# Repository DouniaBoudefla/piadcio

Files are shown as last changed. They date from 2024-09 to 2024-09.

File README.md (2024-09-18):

PIADC-IO

PIADC-IO is a versatile and I/O expansion project designed to enhance the GPIO capabilities of the Raspberry Pi. The project integrates the MCP23S08 I/O expander and the MCP3208 ADC (Analog-to-Digital Converter) with the Raspberry Pi, enabling efficient control of multiple devices and precise analog signal measurements via the SPI protocol. This repository contains all the necessary resources, including schematics, PCB designs, code, and documentation, to set up and use the PIADC-IO system for various applications, such as slow control in experimental setups and monitoring analog inputs.

Features

I/O Expansion: Utilize the MCP23S08 to expand the Raspberry Pi's GPIO capabilities by 8 configurable pins per expander, supporting multiple input/output configurations.
Analog-to-Digital Conversion: Integrate the MCP3208 to enable reading from up to 8 analog input channels with 12-bit resolution.
Power Indication LED: Monitor power status with a controllable LED, which can be managed via the Raspberry Pi.
Modular and Configurable: Easily adapt the system to different hardware setups with a TOML configuration file used to define hardware-specific settings like SPI bus numbers and chip select lines.

Repository Structure

pcb/ - Includes PCB design files and contains the electronic schematics used for the project, designed in KiCad.
src/ - Source code for interacting with the MCP23S08 and MCP3208, including Python classes for each.

Preliminary Configuration

Before starting, you need to enable the SPI function on your Raspberry Pi using 'raspi-config'.
The Raspberry Pi have 2 different SPI bus: one will be known as /dev/spi0.* and the other as /dev/spi1.*.

Enabling SPI1

if '/dev/spi1.0' and '/dev/spi1.1' are not available, you need to enable SPI1 manually:

1. Edit the boot configuration file:

        sudo nano /boot/config.txt

2. Add the following lines at the end of the file to enable SPI1:

        dtparam=spi=on
        dtoverlay=spi1-3cs

3. Save the file and exit the editor (Ctrl + O, Enter, Ctrl + X)
4. Reboot your Raspberry Pi to apply the changes:

        sudo reboot

After rebooting, you should see '/dev/spi1.0' and '/dev/spi1.1' available for use.

Communication with MCP23S08

To communicate with MCP23S08, you need to send and receive data via the SPI interface. Here is how you can read from and write to the the MCP23S08 registers using Python with the 'spidev' library.

Understanding MCP23S08 Communication

Commmand Structure

Communication with the MCP23S08 involves sending a sequence of bytes over the SPI interface. 
Each command generally consists of the following parts:

- Opcode: Determines whether the operation is a read or write
- Register Address: Specifies which register to access
- Data: The value to write to the register (for write operations)

Opcode

Write Opcode: Ox40 (A0=0, A1=0)
Read Opcode: 0x41 (A0=0, A1=0)

The opcode is followed by the register address and then the data byte

Register Address

The MCP23S08 has several registers for configuring and controlling the I/Os. Here are some key registers:

- IODIR (0X00): I/O Direction Register (1 = input, 0 = output)
- GPIO (0x09): GPIO Register (read/write I/O values)
- OLAT (0x0A): Output Latch Register (maintain output values)

Data 

The data byte is the value you write to the register. For read operations, the data byte received from the MCP23S08 will contain the registers's current value.

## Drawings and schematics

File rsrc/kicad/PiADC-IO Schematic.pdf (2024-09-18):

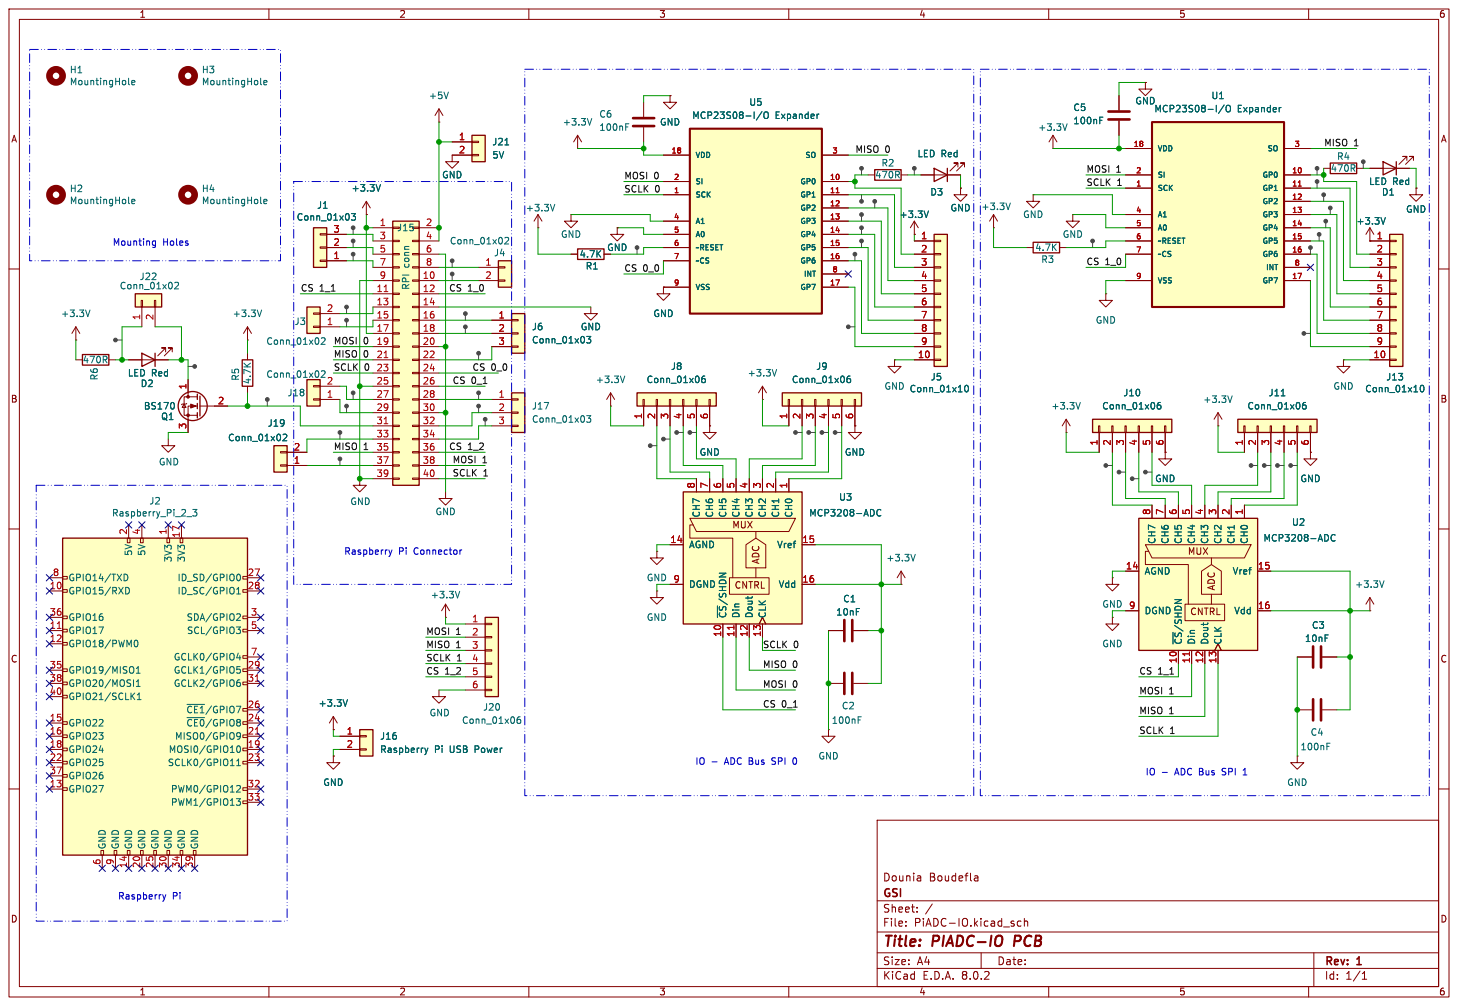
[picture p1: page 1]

6 U1 MCP23S08-I/O Expander SCK 1 GP0 10 GP1 11 GP2 12 GP3 13 GP4 14 GP5 15 GP6 16 GP7 17 VDD 18 SI 2 SO 3 A1 4 A0 5 ~RESET 6 ~CS 7

LED Red GND GND

1 ~{CS}/SHDN 10 Din 11 Dout 12 CLK 13 AGND 14 Vref 15 Vdd 16 CH1

J16 Raspberry Pi USB Power 1

J16 Raspberry Pi USB Power

IO - ADC Bus SPI 0

File: PiADC-IO.kicad_sch Sheet: / GSI Dounia Boudefla

Id: 1/1 Title: PIADC-IO PCB

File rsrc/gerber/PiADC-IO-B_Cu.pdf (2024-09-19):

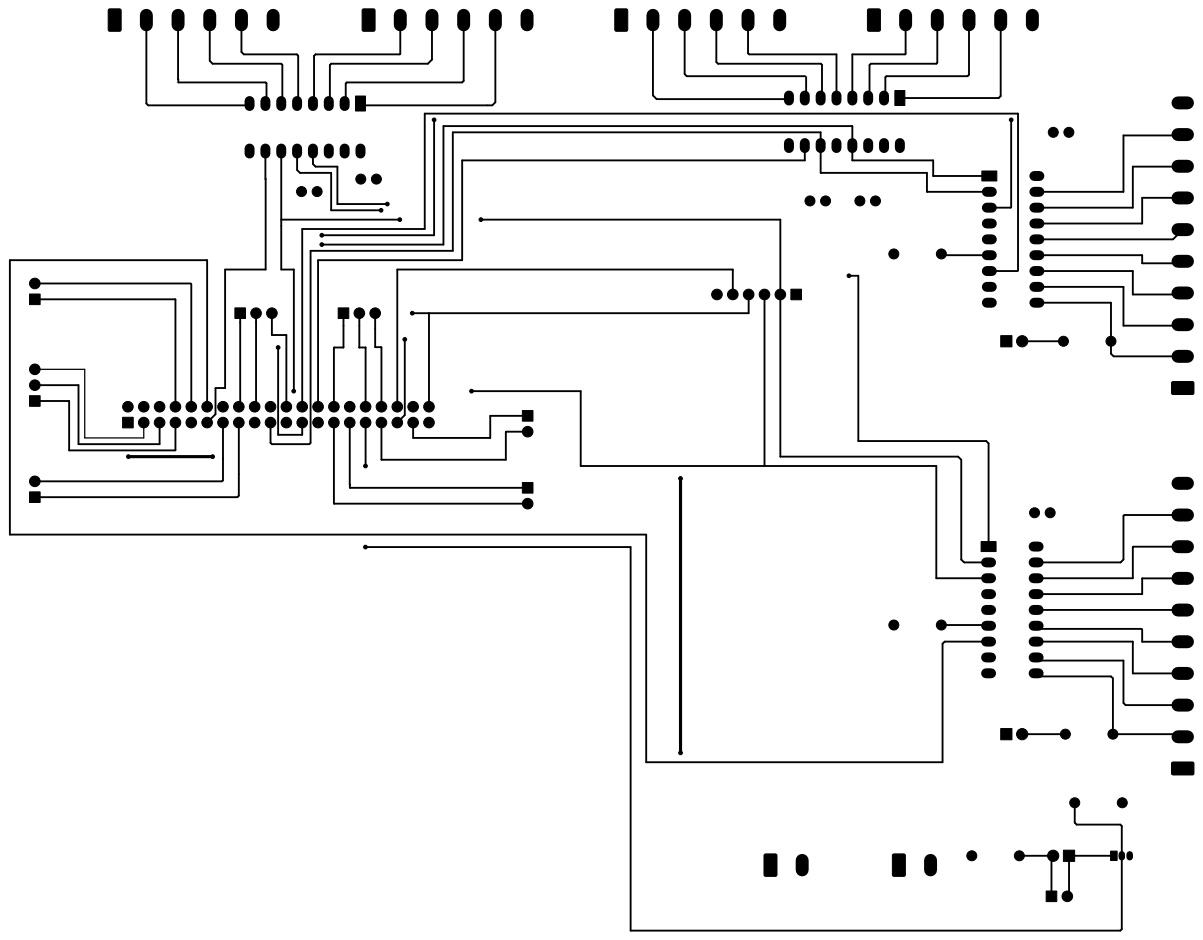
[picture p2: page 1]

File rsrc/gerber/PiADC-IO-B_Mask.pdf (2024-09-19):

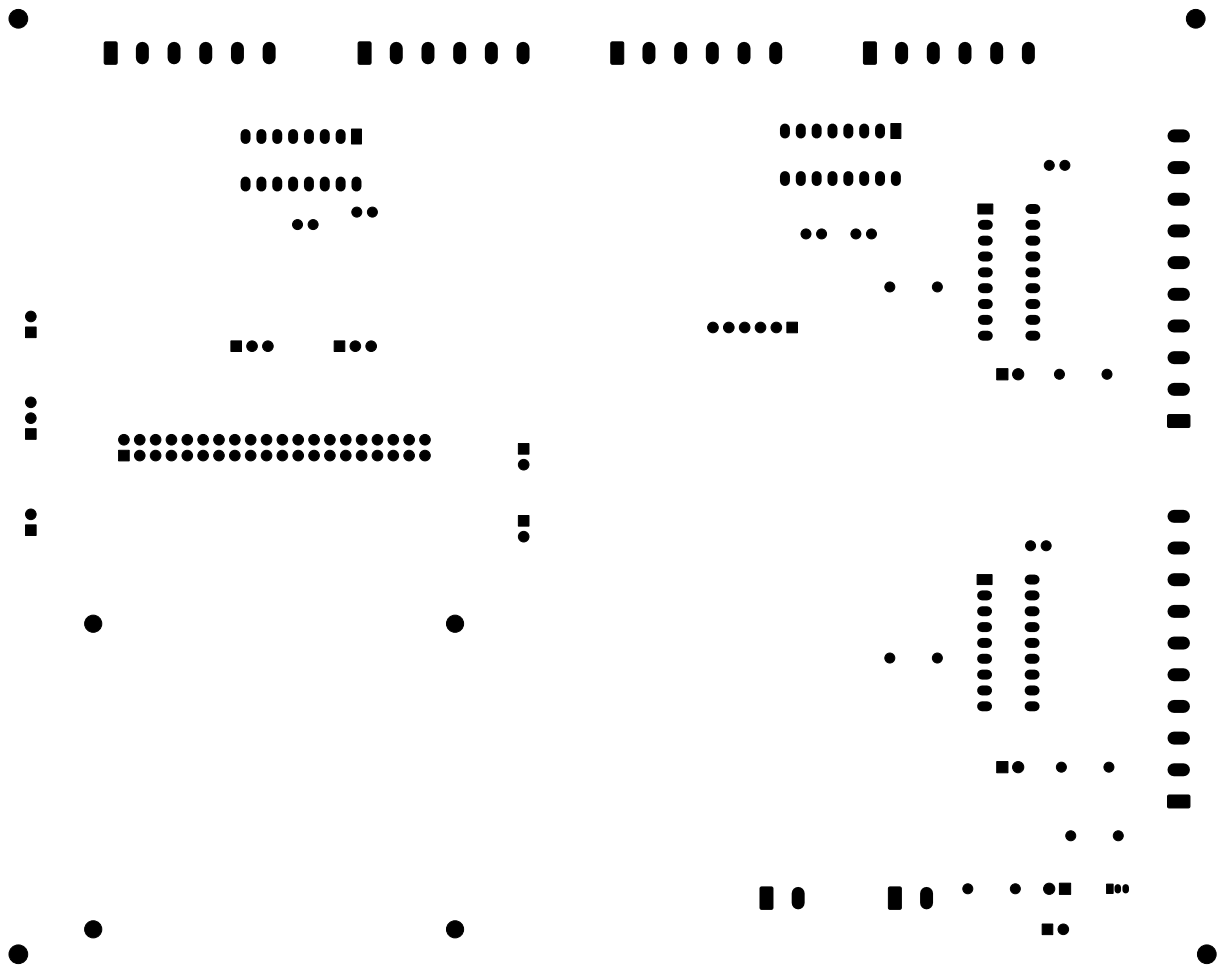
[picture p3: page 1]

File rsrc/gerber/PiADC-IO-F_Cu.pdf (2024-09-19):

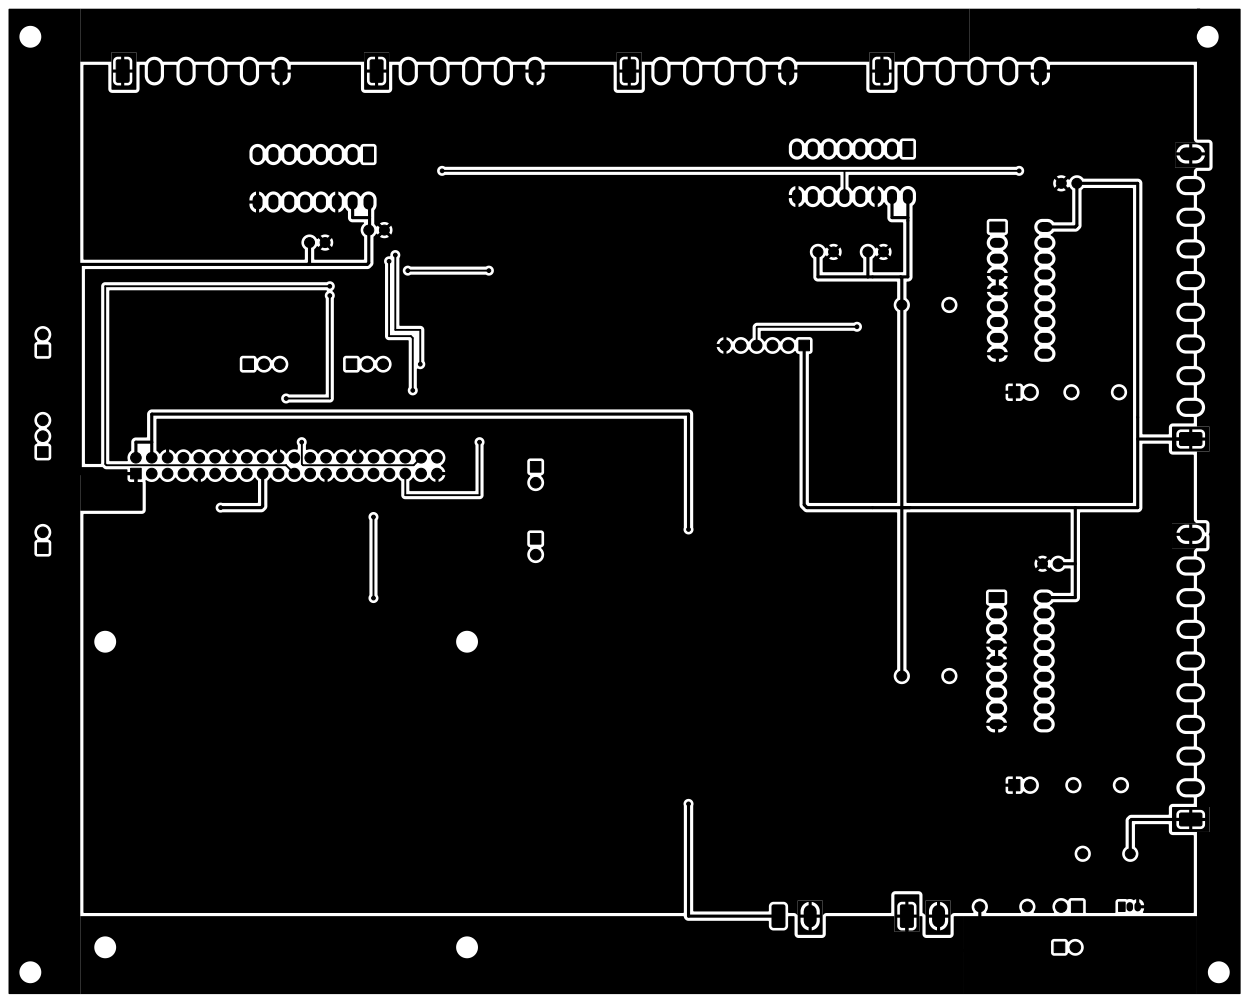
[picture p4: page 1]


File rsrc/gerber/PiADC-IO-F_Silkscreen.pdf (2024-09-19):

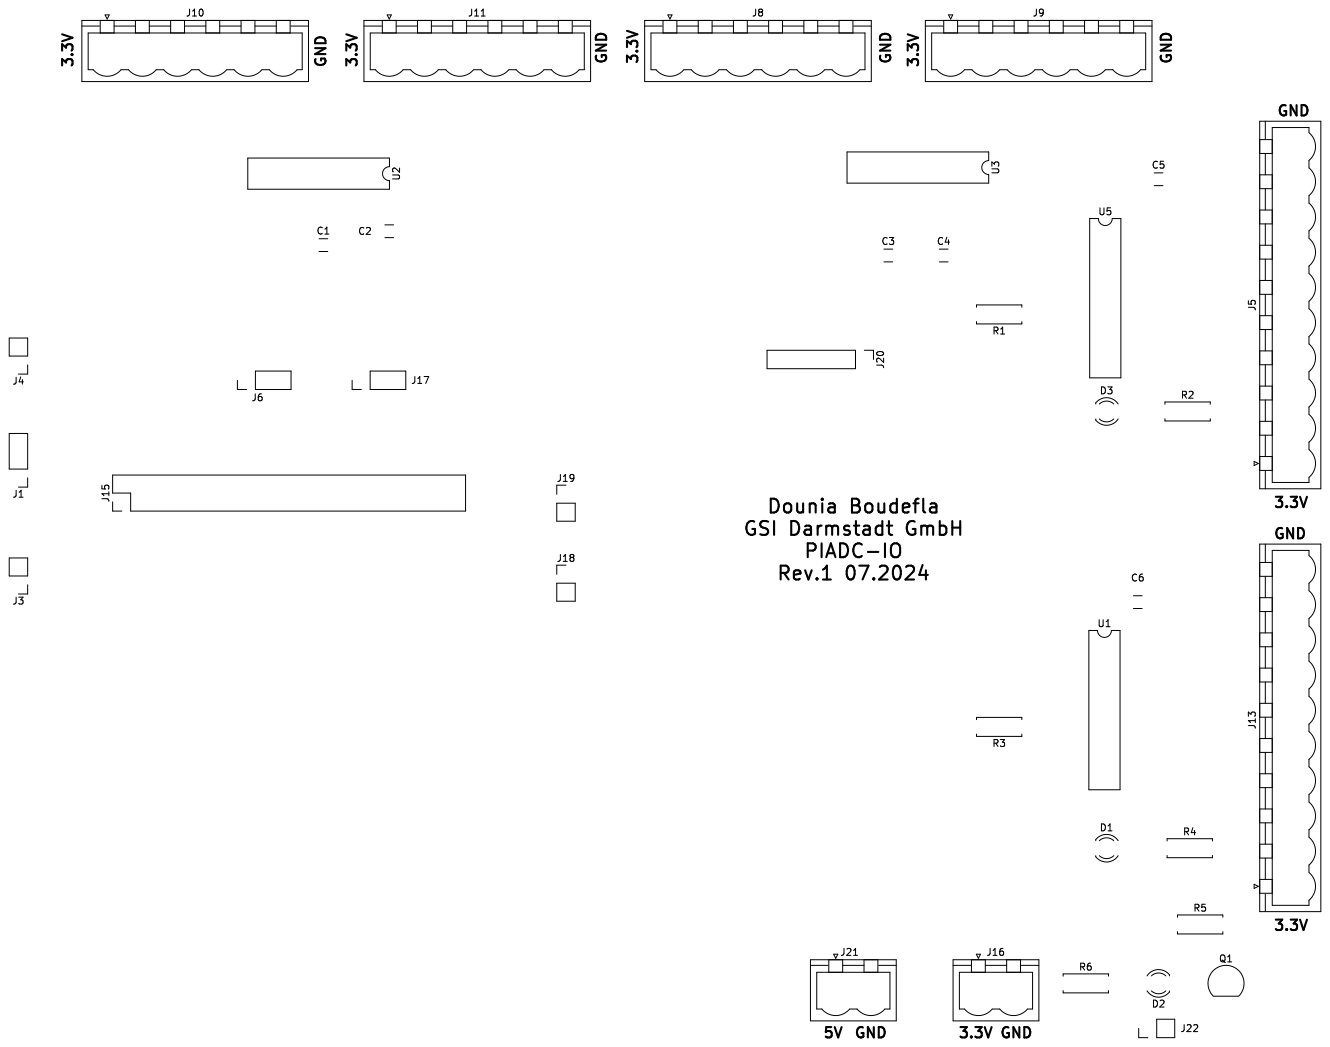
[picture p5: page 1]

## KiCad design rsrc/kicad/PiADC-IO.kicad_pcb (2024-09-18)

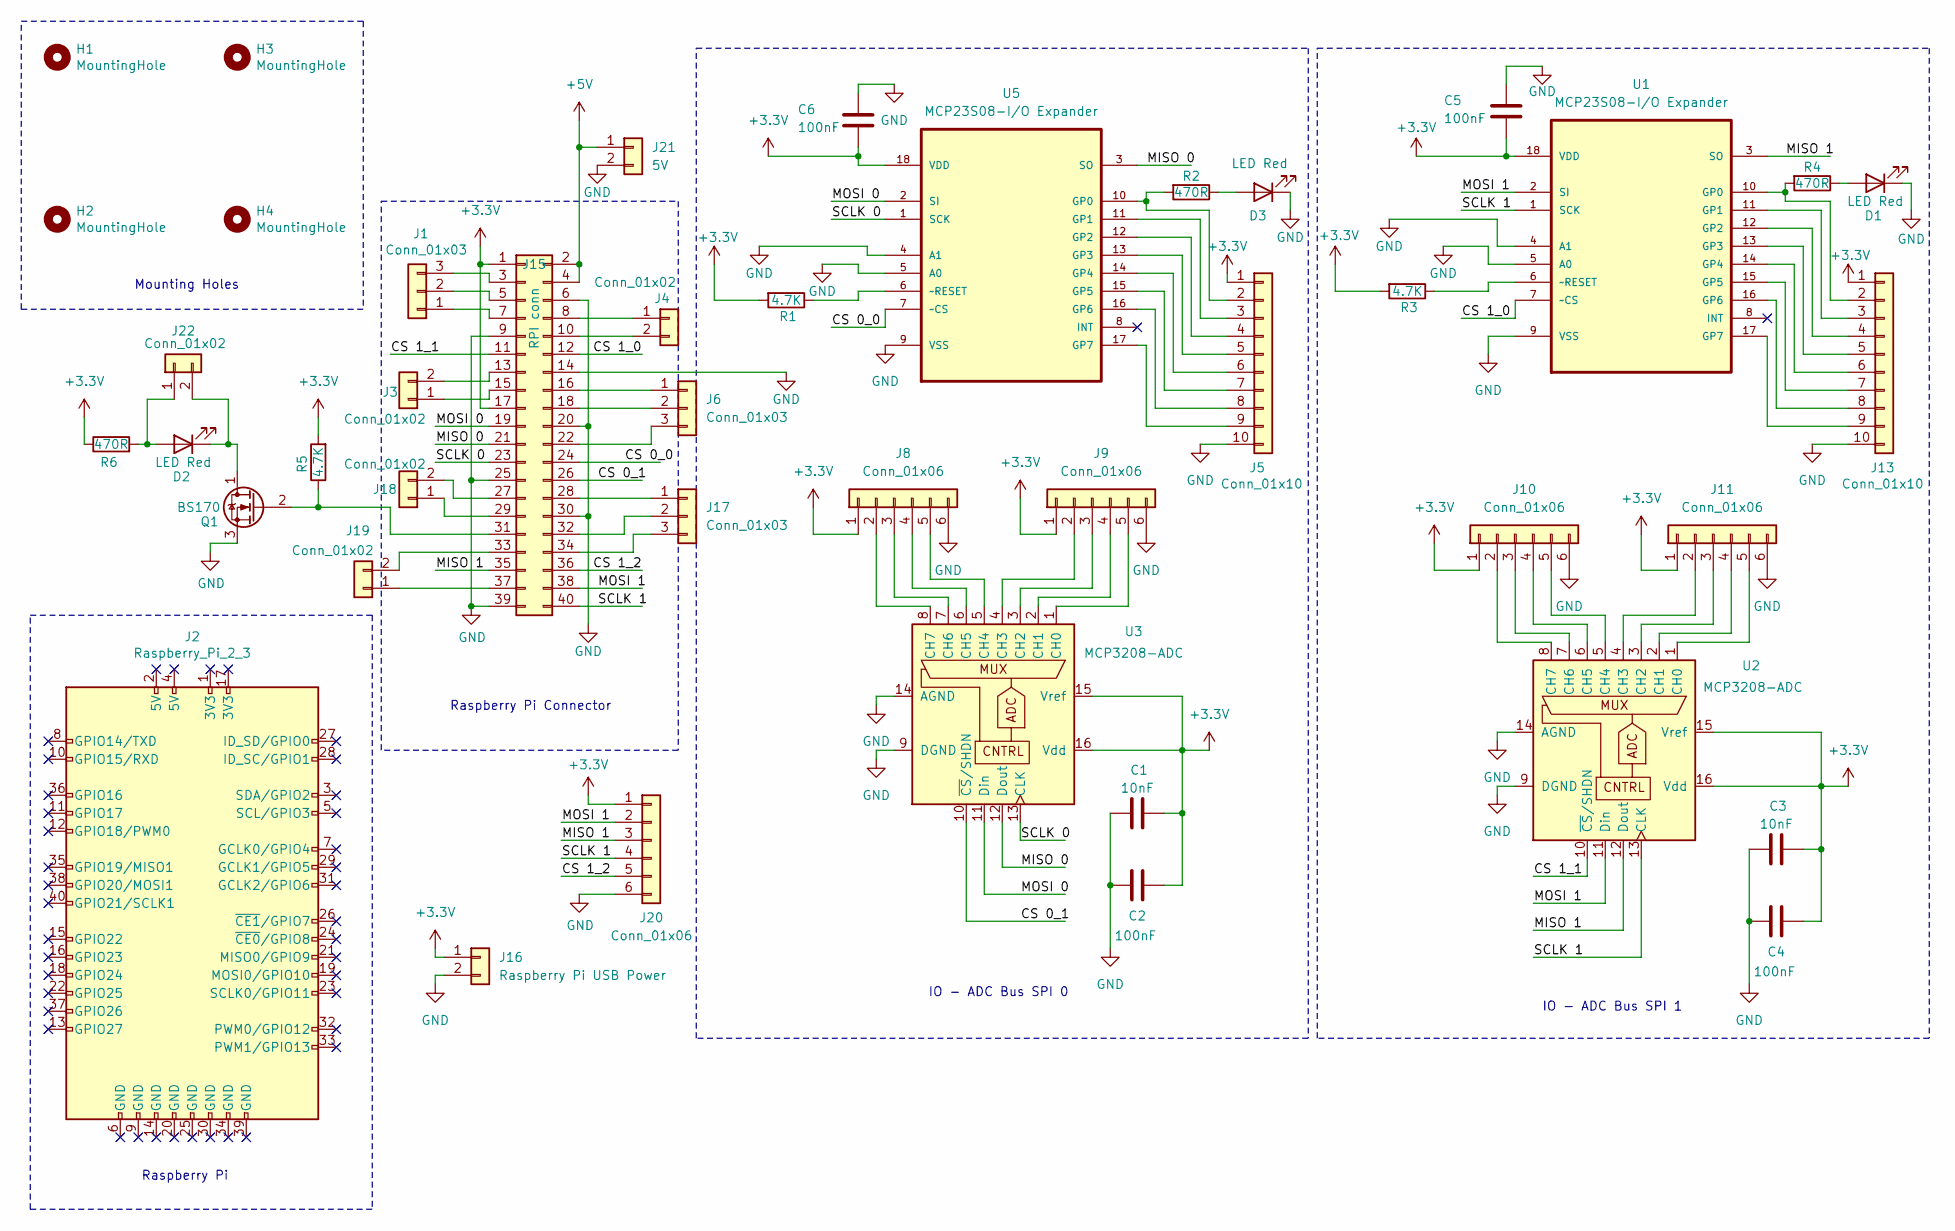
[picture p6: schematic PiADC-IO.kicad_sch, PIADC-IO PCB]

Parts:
C1, C3: 10nF; C_Disc_D3.0mm_W1.6mm_P2.50mm
C2, C4, C5, C6: 100nF; C_Disc_D3.0mm_W1.6mm_P2.50mm
D1, D2, D3: LED Red; LED_D3.0mm
H1, H2, H3, H4: MountingHole; MountingHole_3mm
J1, J6, J17: Conn_01x03; PinHeader_1x03_P2.54mm_Vertical
J2: Raspberry_Pi_2_3; raspberrypi_NOCONNECTOR
J3, J4, J18, J19, J22: Conn_01x02; PinHeader_1x02_P2.54mm_Vertical
J5, J13: Conn_01x10; PhoenixContact_MSTBVA_2,5_10-G-5,08_1x10_P5.08mm_Vertical
J8, J9, J10, J11: Conn_01x06; PhoenixContact_MSTBVA_2,5_6-G-5,08_1x06_P5.08mm_Vertical
J15: RPI conn; PinHeader_2x20_P2.54mm_Vertical
J16: Raspberry Pi USB Power; PhoenixContact_MSTBVA_2,5_2-G-5,08_1x02_P5.08mm_Vertical
J20: Conn_01x06; PinHeader_1x06_P2.54mm_Vertical
J21: 5V; PhoenixContact_MSTBVA_2,5_2-G-5,08_1x02_P5.08mm_Vertical
Q1: BS170; TO-92_Inline
R1, R3, R5: 4.7K; R_Axial_DIN0207_L6.3mm_D2.5mm_P7.62mm_Horizontal
R2, R4, R6: 470R; R_Axial_DIN0207_L6.3mm_D2.5mm_P7.62mm_Horizontal
U1, U5: MCP23S08-I/O Expander; DIP-18_W7.62mm_LongPads; MPN MCP23S08-E/P
U2, U3: MCP3208-ADC; DIP-16_W7.62mm_LongPads

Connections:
+3.3V: C1.1, C2.1, C3.1, C4.1, C5.2, C6.2, J5.1, J8.1, J9.1, J10.1, J11.1, J13.1, J15.1, J15.17, J16.1, J20.1, R1.2, R3.2, R5.2, R6.1, U1.18 (VDD), U2.15 (Vref), U2.16 (Vdd), U3.15 (Vref), U3.16 (Vdd), U5.18 (VDD)
+5V: J15.2, J15.4, J21.1
/CS 0_0: J15.24, U5.7 (~CS)
/CS 0_1: J15.26, U3.10 (~CS/SHDN)
/CS 1_0: J15.12, U1.7 (~CS)
/CS 1_1: J15.11, U2.10 (~CS/SHDN)
/CS 1_2: J15.36, J20.5
/MISO 0: J15.21, U3.12 (Dout), U5.3 (SO)
/MISO 1: J15.35, J20.3, U1.3 (SO), U2.12 (Dout)
/MOSI 0: J15.19, U3.11 (Din), U5.2 (SI)
/MOSI 1: J15.38, J20.2, U1.2 (SI), U2.11 (Din)
/SCLK 0: J15.23, U3.13 (CLK), U5.1 (SCK)
/SCLK 1: J15.40, J20.4, U1.1 (SCK), U2.13 (CLK)
GND: C1.2, C2.2, C3.2, C4.2, C5.1, C6.1, D1.1 (K), D3.1 (K), J5.10, J8.6, J9.6, J10.6, J11.6, J13.10, J15.6, J15.9, J15.14, J15.20, J15.25, J15.30, J15.39, J16.2, J20.6, J21.2, Q1.3 (S), U1.4 (A1), U1.5 (A0), U1.9 (VSS), U2.9 (DGND), U2.14 (AGND), U3.9 (DGND), U3.14 (AGND), U5.4 (A1), U5.5 (A0), U5.9 (VSS)
unnamed: D1.2 (A), R4.1
unnamed: D2.2 (A), J22.1, R6.2
unnamed: D2.1 (K), J22.2, Q1.1 (D)
unnamed: D3.2 (A), R2.1
unnamed: J1.1, J15.7
unnamed: J1.2, J15.5
unnamed: J1.3, J15.3
unnamed: J5.2, R2.2, U5.10 (GP0)
unnamed: J5.3, U5.11 (GP1)
unnamed: J5.4, U5.12 (GP2)
unnamed: J5.5, U5.13 (GP3)
unnamed: J5.6, U5.14 (GP4)
unnamed: J5.7, U5.15 (GP5)
unnamed: J5.8, U5.16 (GP6)
unnamed: J5.9, U5.17 (GP7)
unnamed: J8.2, U3.8 (CH7)
unnamed: J8.3, U3.7 (CH6)
unnamed: J8.4, U3.6 (CH5)
unnamed: J8.5, U3.5 (CH4)
unnamed: J9.2, U3.4 (CH3)
unnamed: J9.3, U3.3 (CH2)
unnamed: J9.4, U3.2 (CH1)
unnamed: J9.5, U3.1 (CH0)
unnamed: J10.2, U2.8 (CH7)
unnamed: J10.3, U2.7 (CH6)
unnamed: J10.4, U2.6 (CH5)
unnamed: J10.5, U2.5 (CH4)
unnamed: J11.2, U2.4 (CH3)
unnamed: J11.3, U2.3 (CH2)
unnamed: J11.4, U2.2 (CH1)
unnamed: J11.5, U2.1 (CH0)
unnamed: J13.2, R4.2, U1.10 (GP0)
unnamed: J13.3, U1.11 (GP1)
unnamed: J13.4, U1.12 (GP2)
unnamed: J13.5, U1.13 (GP3)
unnamed: J13.6, U1.14 (GP4)
unnamed: J13.7, U1.15 (GP5)
unnamed: J13.8, U1.16 (GP6)
unnamed: J13.9, U1.17 (GP7)
unnamed: J4.1, J15.8
unnamed: J4.2, J15.10
unnamed: J3.2, J15.13
unnamed: J3.1, J15.15
unnamed: J6.1, J15.16
unnamed: J6.2, J15.18
unnamed: J6.3, J15.22
unnamed: J15.27, J18.2
unnamed: J15.28, J17.1
unnamed: J15.29, J18.1
unnamed: J15.31, Q1.2 (G), R5.1
unnamed: J15.32, J17.2
unnamed: J15.33, J19.2
unnamed: J15.34, J17.3
unnamed: J15.37, J19.1
unnamed: R3.1, U1.6 (~RESET)
unnamed: R1.1, U5.6 (~RESET)

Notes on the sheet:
IO - ADC Bus SPI 1
Raspberry Pi
Mounting Holes
Raspberry Pi Connector
IO - ADC Bus SPI 0

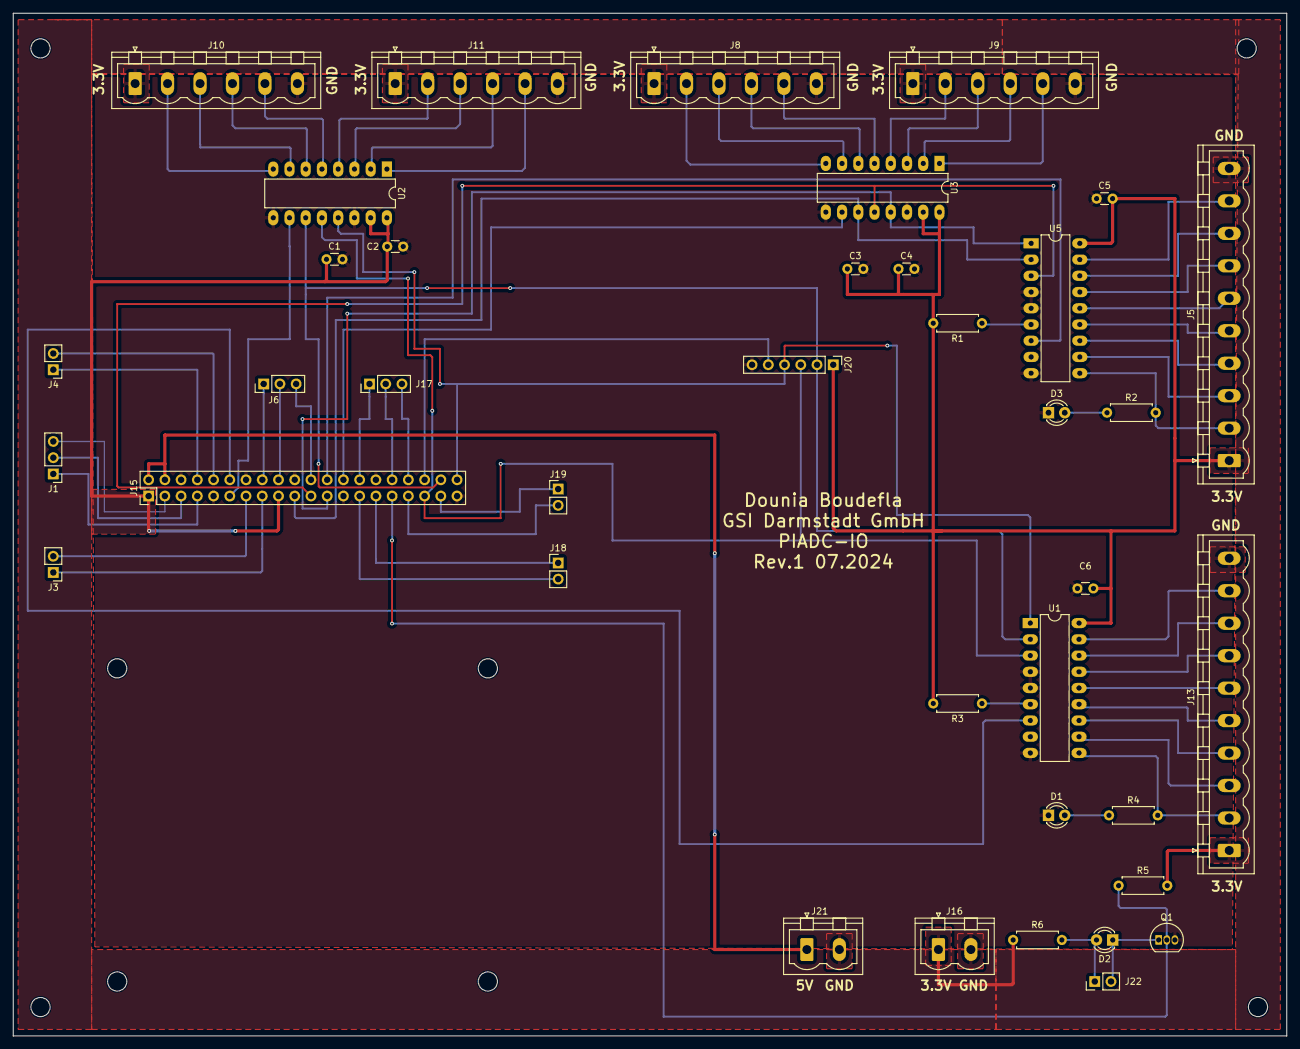
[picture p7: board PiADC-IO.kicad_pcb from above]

Board: 2 copper layers, 199.3 x 160.0 mm, 43 parts (0 on the bottom side), 70 nets.

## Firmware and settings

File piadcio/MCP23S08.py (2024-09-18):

import spidev
import RPi.GPIO as GPIO

# MCP23S08 Registers
REG_IODIR   = 0x00 # I/O DIRECTION REGISTER
REG_IPOL    = 0x01 # INPUT POLARITY REGISTER
REG_GPINTEN = 0x02 # INTERRUPT-ON-CHANGE CONTROL REGISTER
REG_DEFVAL  = 0x03 # DEFAULT COMPARE REGISTER
REG_INTCON  = 0x04 # INTERRUPT CONTROL REGISTER
REG_IOCON   = 0x05 # CONFIGURATION REGISTER
REG_GPPU    = 0x06 # PULL-UP RESISTOR CONFIGURATION REGISTER
REG_INTF    = 0x07 # INTERRUPT FLAG REGISTER
REG_INTCAP  = 0x08 # INTERRUPT CAPTURE REGISTER
REG_GPIO    = 0x09 # PORT REGISTER
REG_OLAT    = 0x0A # OUTPUT LATCH REGISTER

class MCP23S08:
    def __init__(self, spi_bus=0, spi_cs=0, spi_max_speed_hz=5000, cs_pin=24):
        # Initialize SPI
        self.spibus = spidev.SpiDev()
        self.spibus.open(spi_bus, spi_cs)
        self.spibus.max_speed_hz = spi_max_speed_hz

        self.cs_pin = cs_pin

        self._gpio_setup()
    
    def _gpio_setup(self):
        # Turn OFF the warnings
        GPIO.setwarnings(False)

        # We use the board numbering system
        GPIO.setmode(GPIO.BOARD)

        # Setup GPIO for Chip Select
        GPIO.setup(self.cs_pin, GPIO.OUT)
        GPIO.output(self.cs_pin, GPIO.HIGH)
    
    def _spi_write(self, register, value):
        # Write a value in a register
        GPIO.output(self.cs_pin, GPIO.LOW)
        self.spibus.xfer([0x40, register, value])
        GPIO.output(self.cs_pin, GPIO.HIGH)

    def _spi_read(self, register):
        # Read the value from a register
        GPIO.output(self.cs_pin, GPIO.LOW)
        value = self.spibus.xfer([0x41, register, 0x00])
        GPIO.output(self.cs_pin, GPIO.HIGH)
        return value[2]
    
    def set_direction(self, direction):
        # Set the direction of the GPIO pins
        self._spi_write(REG_IODIR, direction)

    def write_in_gpio_pins(self, value):
        # Write a value in GPIO pins
        self._spi_write(REG_GPIO, value)

    def read_all_gpio_pins(self):
        # Read the state of all pins
        return self._spi_read(REG_GPIO)
    
    def print_state_pins(self):
        # Print the state of all pins
        state = self.read_all_gpio_pins()
        temp = 0x01
        for i in range(0,8):
            pin = state & temp
            if pin == temp:
                print("Pin ", i, ' is HIGH \n')
            else:
                print("Pin ", i, "is LOW \n")
            temp = temp << 1

    
    def close(self):
        # Finish the SPI communication and cleanup GPIO
        self.spibus.close()
        GPIO.cleanup()

#-----------------

def main():
    mcp = MCP23S08()
    try:
        print("We set all pins HIGH:\n")
        mcp.set_direction(0x00) # Set all pins as output
        mcp.write_in_gpio_pins(0xff) # Set all pins HIGH
        mcp.print_state_pins() # Print state of all pins

        print("\nWe set all pins LOW:\n")
        mcp.write_in_gpio_pins(0x00) # Set all pins LOW
        mcp.print_state_pins() # Print state of all pins
    except KeyboardInterrupt:
        pass
    finally:
        mcp.close()

if __name__ == "__main__":
    main()





    

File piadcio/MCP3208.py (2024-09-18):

import spidev
import RPi.GPIO as GPIO
import toml

class MCP3208:

    # Inputs and Outputs pins 
    CLK    = 23 # Clock
    DIN    = 19 # Digital in MOSI
    DOUT   = 21 # Digital out MISO

    def __init__(self, spi_bus=0, spi_cs=0, spi_max_speed_hz=5000, cs_pin=24):
        #Initialize SPI
        self.spibus = spidev.SpiDev()
        self.spibus.open(spi_bus,spi_cs)
        self.spibus.max_speed_hz = spi_max_speed_hz

        self.CS = cs_pin

        self._gpio_setup()

    def _gpio_setup(self):
        # Turn OFF Warnings
        GPIO.setwarnings(False)

        # We use board numbering system
        GPIO.setmode(GPIO.BOARD)

        # Set pins CLK/DIN/CS as Outputs
        GPIO.setup(self.CLK, GPIO.OUT)
        GPIO.setup(self.DIN, GPIO.OUT)
        GPIO.setup(self.CS, GPIO.OUT)

        # Set pin for DOUT as Input
        GPIO.setup(self.DOUT, GPIO.IN)

        # Flick the Chip-Select to awake the MCP
        GPIO.output(self.CS, GPIO.HIGH)
        GPIO.output(self.CS, GPIO.LOW)
        GPIO.output(self.CLK, GPIO.LOW)

    def read_adc_channel(self, spi, channel):
        (msg_up, msg_dn) = (
            (0x06, 0x00) if channel == 0
            else (0x06, 0x40) if channel == 1
            else (0x06, 0x80) if channel == 2
            else (0x06, 0xC0) if channel == 3
            else (0x07, 0x00) if channel == 4
            else (0x07, 0x40) if channel == 5
            else (0x07, 0x80) if channel == 6
            else (0x07, 0xC0) 
        )

        resp = spi.xfer([msg_up, msg_dn,0x00])
        value = (resp[1] << 8) + resp[2]
        value = int(value)

        if value <= 0:
            value = 0
        elif value > 4095:
            value = 4095

        return value
    
    def read_all_adc_channels(self, spi, config): 
        num_average = config['num_average']

        values = [0]*8

        # We do multiple measurements and average
        for i in range(num_average):
            for channel in range(8):
                values[channel] += self.read_adc_channel(channel)
        return [int(value / num_average) for value in values]
    
    def close(self):
        self.spibus.close()
        GPIO.cleanup()

    def read_config(config_file):
        # load config file
        with open(config_file, "r") as f:
            config = toml.load(f)
        return config

#-----------------
from time import sleep

def main():
    adc = MCP3208()
    try:
        while True: 
            value = adc.read_adc_channel(adc.spibus, 0)
            print("Value for channel 0: ")
            print(value)

            config = adc.read_config()
            values = adc.read_all_adc_channels(adc.spibus, config)
            print("Values for all channels: ")
            print(values)

            sleep(1)

    except KeyboardInterrupt:
        pass
    finally:
        adc.close()

if __name__ == "__main__":
    main()
